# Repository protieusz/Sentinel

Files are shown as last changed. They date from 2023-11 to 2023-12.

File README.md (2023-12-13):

# Sentinel
A 37 column stagger unisplit keyboard with 25mm or 34mm trackball powered by Omega Supreme Rev 4 all in one module and Universal daughterboard card C3

The Sentinel PCB is sponsored by PCBWay.
PCBWay is your one stop location for all your PCB needs.  High quality PCBA soldering service.  Thank you PCBWay!

3DP trackball holder is designed by @ma_po_daisuki and his designs are being sold at [his Booth store](https://ma-po.booth.pm/items/5258743) which cost around $10 cad. Go check it out and support him.

This build requires a lot of fitness and DIY fixes since I made an oversight as to float mount my all in one mcu, OmegaSupreme that cause small issues like once you solder the switches, it will be super hard to reach the bolt that hold the screws in place on the opposite side. So you will have to tighten the screw real good or add solder to the pads and the bolt itself to secure it so in the future it does not loosen and you will get a short from the loose bolt in between the switch plate and the pcb. My PCBs are designed to tailor my purpose only so if you want to print and build, please do so at your own risk. Lots of time have been invested in designing this pcb and the whole package. It is now fully working with DIY mods. Overall case thickness would either need to be increase by around 1-2mm or you would modify the bottom plate by cutting a 0.8mm dent to the 1.6mm thick bottom plate to accomodate the J2 4 pin plug that sticks out a bit that causes one section of the bottom case to stick out. I might or might not create a fix in the future. Files will me made public soon and you guys can modify it.  The wire for the daughterboard is a tight fit but doable so please be careful adjustin gthe wire slack since the FR4 is sharp and can cut the thin wires for the daughterboard card.

QMK firmware and source code is borrowed from Aki27's bally so everything is still the same except the keymapping and the matrix, etc. No support is given. Please ask the original author for help if there are issues. It is working very good and I am using it as daily driver.

Featured on https://kbd.news/Sentinel-2220.html

Final Build Pictures December 7, 2023:









Build Process:

























Made an oversight mistake on the spacing the sensor and the flash chip. Apparently when closing the bottom switch plate, there was a bulge.  So it turns out that overall thickness of the case needs to be increase by around 1mm to 1.2mm to accomodate for the flash chip and the mouse sensor.  So I had to DIY melt cut square holes on the bottom case. In the future I might correct the case by adding 1.2mm to the thickness.  Right now this is a temporary fix.  Designing is not as easy as it seems. You cannot foresee any future hiccups.










Unboxing










Switchplate Test Fit:





FUSION360 & EasyEDA PCB Rendering:

Screenshot 2023-12-04 at 10 48 55 AM
Mech silkscreen icon borrowed from [Adobe Stock](https://stock.adobe.com/ca/images/giant-mecha-robot-or-battle-bot-set-collection-vector-icons-illustrations-of-gigantic-mechanical-machine-or-big-mech-robots-for-war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) 

Screenshot 2023-11-20 at 10 33 51 AM
Screenshot 2023-11-20 at 10 34 07 AM
Screenshot 2023-11-20 at 10 35 12 AM
Screenshot 2023-11-20 at 10 35 28 AM
Screenshot 2023-11-20 at 10 35 46 AM

Estimate 25mm trackball height to the mock up keycap height. Pretty low profile. Good for the hands.
Screenshot 2023-11-20 at 10 44 41 AM
Screenshot 2023-11-20 at 10 44 24 AM

Screenshot 2023-11-19 at 11 41 39 AM
Screenshot 2023-11-19 at 11 41 28 AM
Screenshot 2023-11-19 at 11 41 05 AM
Screenshot 2023-11-19 at 11 39 56 AM
Screenshot 2023-11-19 at 11 39 39 AM
Screenshot 2023-11-19 at 11 39 22 AM
Screenshot 2023-11-19 at 11 38 54 AM
Screenshot 2023-11-19 at 11 38 30 AM
Screenshot 2023-11-19 at 11 38 07 AM
Screenshot 2023-11-19 at 9 09 04 AM
Screenshot 2023-11-19 at 9 08 25 AM

Trackball Test Fitting:




Initial Prototyping Test:



# License

</a></p>

You are free to:

Share — copy and redistribute the material in any medium or format

Adapt — remix, transform, and build upon the material

The licensor cannot revoke these freedoms as long as you follow the license terms.
Under the following terms:

Attribution — You must give appropriate credit, provide a link to the license, and indicate if changes were made. You may do so in any reasonable manner, but not in any way that suggests the licensor endorses you or your use.

NonCommercial — You may not use the material for commercial purposes.

ShareAlike — If you remix, transform, or build upon the material, you must distribute your contributions under the same license as the original.

No additional restrictions — You may not apply legal terms or technological measures that legally restrict others from doing anything the license permits.

Sentinel by ProtieusKeebs is licensed under [CC BY-NC-SA 4.0](https://creativecommons.org/licenses/by-nc-sa/4.0/?ref=chooser-v1)

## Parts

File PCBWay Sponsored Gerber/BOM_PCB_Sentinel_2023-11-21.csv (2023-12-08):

ID | Name | Designator | Footprint | Quantity | Manufacturer Part | Manufacturer | Supplier | Supplier Part | Price | link
1 | SM4007PL | D207,D100,D101,D102,D103,D104,D106,D107,D108,D109,D110,D200,D201,D202,D203,D204,D206,D208,D209,D210,D302,D303,D304,D305,D306,D307,D308,D000,D001,D002,D003,D004,D006,D007,D008,D009,D010 | SOD-123F_L2.8-W1.8-LS3.7-RD | 37 | SM4007PL | MDD | LCSC | C64898 | 0.007 | https://item.szlcsc.com/60254.html
2 | Switch | K100,K101,K102,K103,K104,K106,K107,K108,K109,K110,K200,K201,K202,K203,K204,K206,K207,K208,K209,K210,K302,K303,K304,K305,K306,K307,K308,K000,K001,K002,K003,K004,K006,K007,K008,K009,K010 | CHERRY_MX_100_MILLMAX | 37 |  |  |  |  |  | Do Not Need To Assemble
3 | OSLEFT | LEFT1 | FPC-SMD_FH12-12S-0.5SH-55 | 1 | FH12-12S-0.5SH(55) | HRS(广濑) | LCSC | C88360 | 0.428 | https://lcsc.com/eda_search?q=C88360&%26type=1&ref=editor
4 | OSRight | RIGHT1 | FPC-SMD_FH12-12S-0.5SH-55 | 1 | FH12-12S-0.5SH(55) | HRS(广濑) | LCSC | C88360 | 0.428 | https://lcsc.com/eda_search?q=C88360&%26type=1&ref=editor

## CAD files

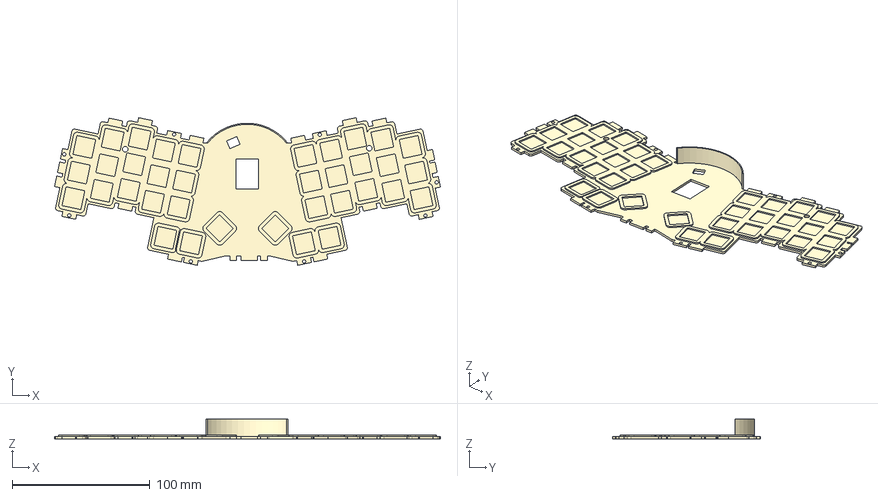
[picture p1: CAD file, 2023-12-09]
STEP Files/SentinelBottomPlateHoles.step
280.7 x 107.4 x 14.2 mm

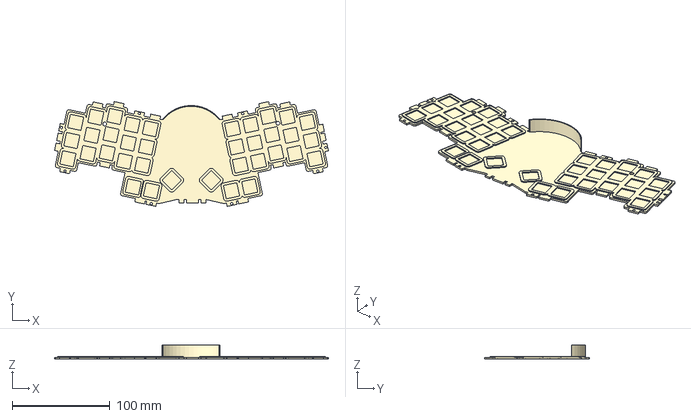
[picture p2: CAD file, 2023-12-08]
STEP Files/SentinelBottomCase.step
280.7 x 107.4 x 14.2 mm

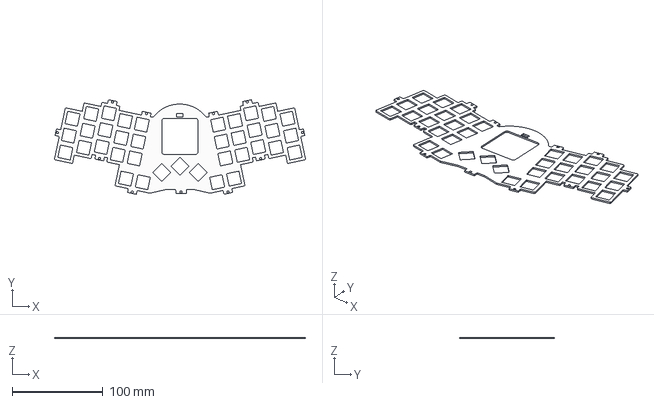
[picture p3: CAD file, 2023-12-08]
STEP Files/SentinelSwitchPlate.step
277.1 x 104.5 x 1.50 mm

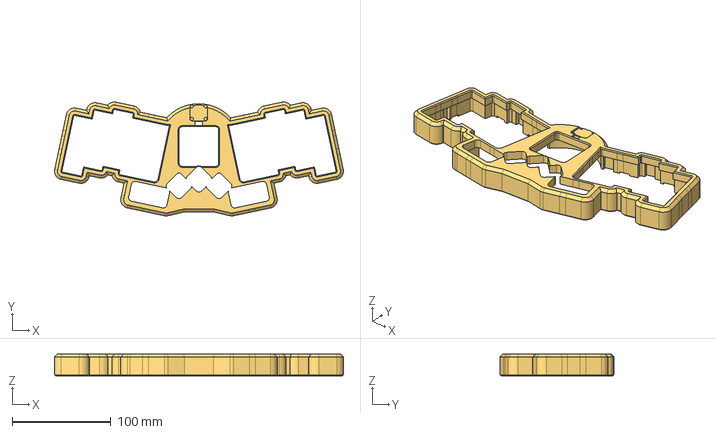
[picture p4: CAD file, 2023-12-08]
STEP Files/SentinelTopCase.step
292.1 x 115.2 x 22.2 mm

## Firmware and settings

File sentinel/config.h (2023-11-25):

// Copyright 2023 aki27 (@aki27kbd)
// SPDX-License-Identifier: GPL-2.0-or-later

#pragma once

//#define VIAL_KEYBOARD_UID {0xC4, 0x18, 0xCC, 0x6D, 0x1C, 0x16, 0x5B, 0x8D}
//#define VIAL_UNLOCK_COMBO_ROWS {0, 0}
//#define VIAL_UNLOCK_COMBO_COLS {1, 11}

/* VIA */
//#define DYNAMIC_KEYMAP_LAYER_COUNT 8


/* key matrix size */
//#define MATRIX_COLS 13
//#define MATRIX_ROWS 4


/* tapping term */
// #define TAPPING_FORCE_HOLD
//#define TAPPING_TERM 200
// #define IGNORE_MOD_TAP_INTERRUPT

#define RP2040_BOOTLOADER_DOUBLE_TAP_RESET // Activates the double-tap behavior
#define RP2040_BOOTLOADER_DOUBLE_TAP_RESET_TIMEOUT 200U // Timeout window in ms in which the double tap can occur.

#ifdef COMBO_ENABLE
#    define COMBO_COUNT 6
#    define COMBO_TERM 200
#endif

/* Encoder */
//#define ENCODERS_PAD_A { GP11 }
//#define ENCODERS_PAD_B { GP12 }
//#define ENCODER_RESOLUTION 4

/* Matrix*/
//#define MATRIX_COL_PINS { GP25, GP24, GP23, GP22, GP21, GP26, GP27, GP20, GP19, GP18, GP17, GP16, GP13 }
//#define MATRIX_ROW_PINS { GP28, GP10, GP14, GP15 }

/* COL2ROW, ROW2COL */
//#define DIODE_DIRECTION COL2ROW


/* Set 0 if debouncing isn't needed */
//#define DEBOUNCE 5


/* Mechanical locking support. Use KC_LCAP, KC_LNUM or KC_LSCR instead in keymap (Very Important for Scroll Lock!!!) */
#undef LOCKING_SUPPORT_ENABLE
/* Locking resynchronize hack */
#undef LOCKING_RESYNC_ENABLE


/* RGB LED */
//#define WS2812_PIO_USE_PIO1
#define WS2812_DI_PIN GP29

#ifdef RGBLIGHT_ENABLE
    #define RGBLED_NUM 42
    #define RGBLIGHT_LIMIT_VAL 255
    #define RGBLIGHT_HUE_STEP 10
    #define RGBLIGHT_SAT_STEP 17
    #define RGBLIGHT_VAL_STEP 17

    // #define RGBLIGHT_ANIMATIONS
    #define RGBLIGHT_EFFECT_BREATHING
    #define RGBLIGHT_EFFECT_RAINBOW_MOOD
    #define RGBLIGHT_EFFECT_RAINBOW_SWIRL
    #define RGBLIGHT_EFFECT_SNAKE
    #define RGBLIGHT_EFFECT_KNIGHT
    #define RGBLIGHT_EFFECT_CHRISTMAS
    #define RGBLIGHT_EFFECT_STATIC_GRADIENT
    #define RGBLIGHT_EFFECT_TWINKLE
    #define RGBLIGHT_EFFECT_ALTERNATING
#endif


/* Trackball */

#ifdef POINTING_DEVICE_ENABLE

//#    undef RP_SPI_USE_SPI0
//#    define RP_SPI_USE_SPI0 TRUE
//#    undef RP_SPI_USE_SPI1
//#    define RP_SPI_USE_SPI1 FALSE
#    define SPI_DRIVER SPID0

//#    define SPI_SCK_PIN GP22 //6
//#    define SPI_MISO_PIN GP24 //4
//#    define SPI_MOSI_PIN GP23 //7
#    define SPI_SCK_PIN GP18
#    define SPI_MISO_PIN GP16
#    define SPI_MOSI_PIN GP19

#endif


#ifndef PMW33XX_CS_PIN
#    define PMW33XX_CS_PIN GP17
#endif
#define POINTING_DEVICE_INVERT_X
#define POINTING_DEVICE_INVERT_Y
//#define ROTATIONAL_TRANSFORM_ANGLE 90
#define POINTING_DEVICE_ROTATION_180

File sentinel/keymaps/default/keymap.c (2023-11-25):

/*
Copyright 2022 aki27

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
You should have received a copy of the GNU General Public License
along with this program.  If not, see <http://www.gnu.org/licenses/>.
*/

#include QMK_KEYBOARD_H

enum combo_events {
  COMBO_DEL,
  COMBO_ESC,
  COMBO_CTRL,
  COMBO_ALT,
  COMBO_LENGTH
};
uint16_t COMBO_LEN = COMBO_LENGTH;

const uint16_t PROGMEM combo_del[] = {KC_Y, KC_H, COMBO_END};
const uint16_t PROGMEM combo_esc[] = {KC_T, KC_G, COMBO_END};
const uint16_t PROGMEM combo_ctrl[] = {KC_Q, KC_W, COMBO_END};
const uint16_t PROGMEM combo_alt[] = {KC_O, KC_P, COMBO_END};

combo_t key_combos[] = {
  [COMBO_DEL] = COMBO(combo_del, KC_DEL),
  [COMBO_ESC] = COMBO(combo_esc, KC_ESC),
  [COMBO_CTRL] = COMBO(combo_ctrl, KC_LCTL),
  [COMBO_ALT] = COMBO(combo_alt, KC_RALT),

};

layer_state_t layer_state_set_user(layer_state_t state) {
    return update_tri_layer_state(state, 1, 2, 3);
} 

enum layer_names {
  _BASE,
  _FN1,
  _FN2,
  _FN3
};

const uint16_t PROGMEM keymaps[][MATRIX_ROWS][MATRIX_COLS] = {
    
    [_BASE] = LAYOUT(
        KC_Q,         KC_W, KC_E,    KC_R,    KC_T,                                              KC_Y,          KC_U,          KC_I,     KC_O,   KC_P,
        KC_A,         KC_S, KC_D,    KC_F,    KC_G,                                              KC_H,          KC_J,          KC_K,     KC_L,   KC_SCLN,
        LSFT_T(KC_Z), KC_X, KC_C,    KC_V,    KC_B,                                              KC_N,          KC_M,          KC_COMMA, KC_DOT, RSFT_T(KC_SLSH),
                                     KC_LGUI, LT(1,KC_BSPC), KC_MS_BTN2, KC_MS_BTN1, SCRL_MO,    LT(2,KC_SPC),  (KC_ENT)                        
    ),
    [_FN1] = LAYOUT(
        KC_1,    KC_2,    KC_3,    KC_4,    KC_5,                                     KC_6,     KC_7,    KC_8,    KC_9,    KC_0,
        KC_TAB,  _______, _______, _______, _______,                                  KC_MINS,  KC_EQL,  KC_LBRC, KC_RBRC, KC_QUOT,
        _______, _______, KC_MUTE, KC_VOLD, KC_VOLU,                                  KC_TILD,  KC_GRV,  _______, _______, KC_BSLS,
                                     _______, _______,     _______, _______, _______,   _______,  _______                   
    ),
    [_FN2] = LAYOUT(
        KC_EXLM, KC_AT,   KC_HASH, KC_DLR,  KC_PERC,                                            KC_CIRC, KC_AMPR, KC_ASTR, KC_LPRN, KC_RPRN,
        RGB_VAI,  RGB_SAI,    RGB_HUI,    RGB_SPI,   RGB_MOD,                                   RGB_TOG,  _______,  _______, _______, _______, 
        RGB_VAD,  RGB_SAD,    RGB_HUD,    RGB_SPD,   RGB_RMOD,                                  _______,  _______, _______, _______, _______,
                                          _______, _______,     _______, _______, _______,   _______,  _______                   
    ),
    [_FN3] = LAYOUT(
        _______, KC_UP, _______, _______, _______,                                   KC_F1,   KC_F2,   KC_F3,   KC_F4,   KC_PSCR,
        KC_LEFT, KC_DOWN, KC_RIGHT, _______, _______,                                KC_F5,   KC_F6,   KC_F7,   KC_F8,   KC_F9,
        _______, _______, ROT_L15, ROT_R15, CPI_SW,                                  KC_F10,  KC_F11,  KC_F12,  _______, _______,
                                          _______, _______,     _______, _______, _______,   _______, _______                   
    )
};

//bool encoder_update_user(uint8_t index, bool clockwise) {
    //if (index == 0) {
        //if (clockwise) {
            //tap_code(KC_VOLD);
            //tap_code(KC_MS_WH_UP);
        //} else {
            //tap_code(KC_VOLU);
            //tap_code(KC_MS_WH_DOWN);
        //}
    //}
    //return true;
//}

/* My Encoder Codes */
//#if defined(ENCODER_MAP_ENABLE)
//const uint16_t PROGMEM encoder_map[][NUM_ENCODERS][2] = {
    //[0] =  { ENCODER_CCW_CW(KC_MS_WH_UP, KC_MS_WH_DOWN)  },
    //[1] =  { ENCODER_CCW_CW(KC_MS_WH_LEFT, KC_MS_WH_RIGHT)  },
    //[2] =  { ENCODER_CCW_CW(KC_PGUP, KC_PGDN)  },
    //[3] =  { ENCODER_CCW_CW(KC_VOLD, KC_VOLU)  } 
    //[4] =  { ENCODER_CCW_CW(XXXXXXX, XXXXXXX) }
//};
//#endif

//keyevent_t encoder1_ccw = {
    //.key = (keypos_t){.row = 3, .col = 0},
    //.pressed = false
//};

//keyevent_t encoder1_cw = {
    //.key = (keypos_t){.row = 3, .col = 9},
    //.pressed = false
//};

//bool encoder_update_user(uint8_t index, bool clockwise) {
    //if (index == 0) { /* First encoder */
        //if (clockwise) {
            //encoder1_cw.pressed = true;
            //encoder1_cw.time = (timer_read() | 1);
            //action_exec(encoder1_cw);
        //} else {
            //encoder1_ccw.pressed = true;
            //encoder1_ccw.time = (timer_read() | 1);
            //action_exec(encoder1_ccw);
        //}
    //}

    //return true;
//}

//void matrix_scan_user(void) {

    //if (IS_PRESSED(encoder1_ccw)) {
        //encoder1_ccw.pressed = false;
        //encoder1_ccw.time = (timer_read() | 1);
        //action_exec(encoder1_ccw);
    //}

    //if (IS_PRESSED(encoder1_cw)) {
        //encoder1_cw.pressed = false;
        //encoder1_cw.time = (timer_read() | 1);
        //action_exec(encoder1_cw);
    //}

//}

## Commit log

2023-12-08 Production Gerbers
    [BOM_PCB_Sentinel_2023-11-21.csv, PickAndPlace_PCB_Sentinel_2023-11-21.csv]
2023-12-08 Case Files
    [SentinelBottomCase.step, SentinelSwitchPlate.step, SentinelTopCase.step]
2023-12-09 Use this bottomcase instead
    Holes cut out for the sensor and J2 connector so the plate stays flush
2023-12-09 latest revision
    Cut out holes for J2 connector and sensor
    [SentinelBottomPlateHoles.step]
2024-02-17 Removed the mech logo
    [BOM_PCB_Sentinel_2023-11-21.csv, PickAndPlace_PCB_Sentinel_2023-11-21.csv]

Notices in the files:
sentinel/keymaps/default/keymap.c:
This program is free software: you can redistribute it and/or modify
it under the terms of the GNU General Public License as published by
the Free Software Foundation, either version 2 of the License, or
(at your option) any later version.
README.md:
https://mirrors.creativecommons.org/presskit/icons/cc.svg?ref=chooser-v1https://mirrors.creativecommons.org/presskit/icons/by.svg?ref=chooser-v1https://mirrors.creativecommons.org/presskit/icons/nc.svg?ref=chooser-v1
